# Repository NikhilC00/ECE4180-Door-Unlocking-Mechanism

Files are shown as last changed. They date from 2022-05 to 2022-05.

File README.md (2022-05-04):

# ECE4180-Door-Unlocking-Mechanism

Team Members: Audrey Ahlenius and Nikhil Chittaluru

## What is it?

**Problem**: Automatic locking doors in Georgia Tech housing buildings result in students getting locked out

**Solution**: A product that will unlock your door via bluetooth or a touch pad

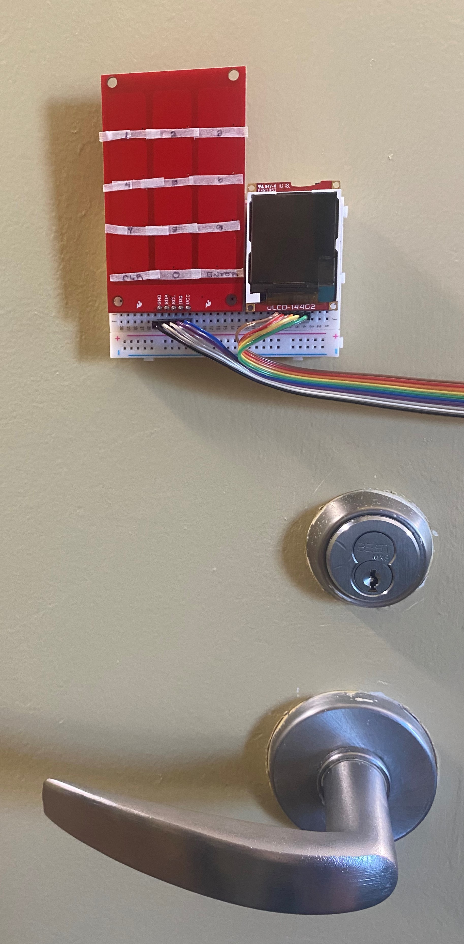
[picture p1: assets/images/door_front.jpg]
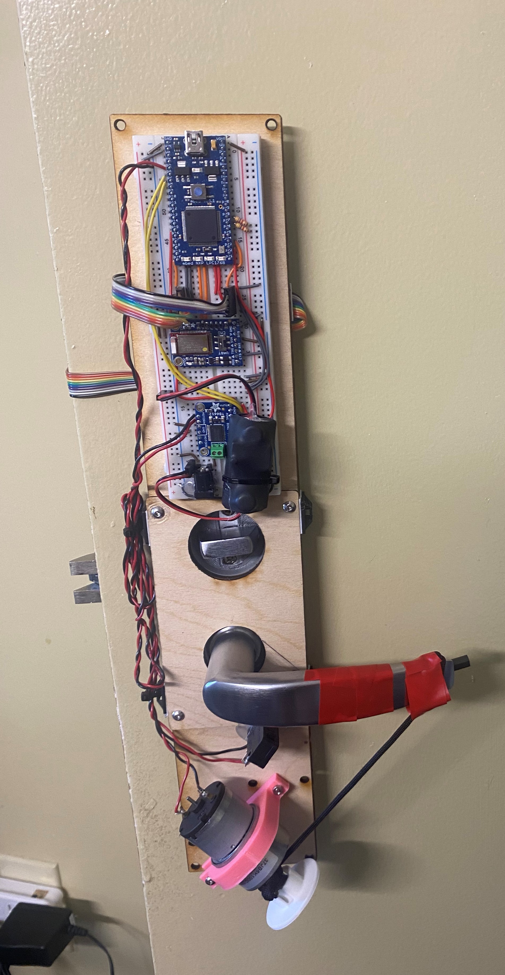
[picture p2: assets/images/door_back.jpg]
 

## Hardware

Here is what our system looks like:

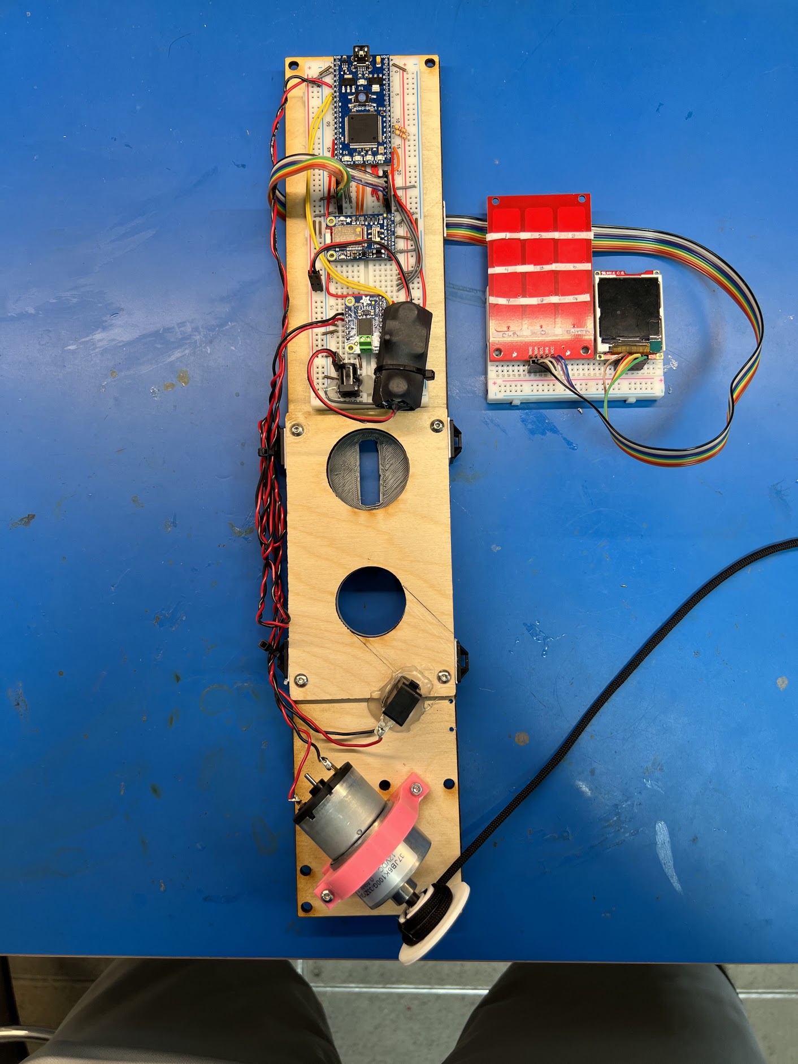
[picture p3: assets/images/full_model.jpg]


**Modules**: Main Electronics Board, Door UI, Door Handle Motor (from left to right)

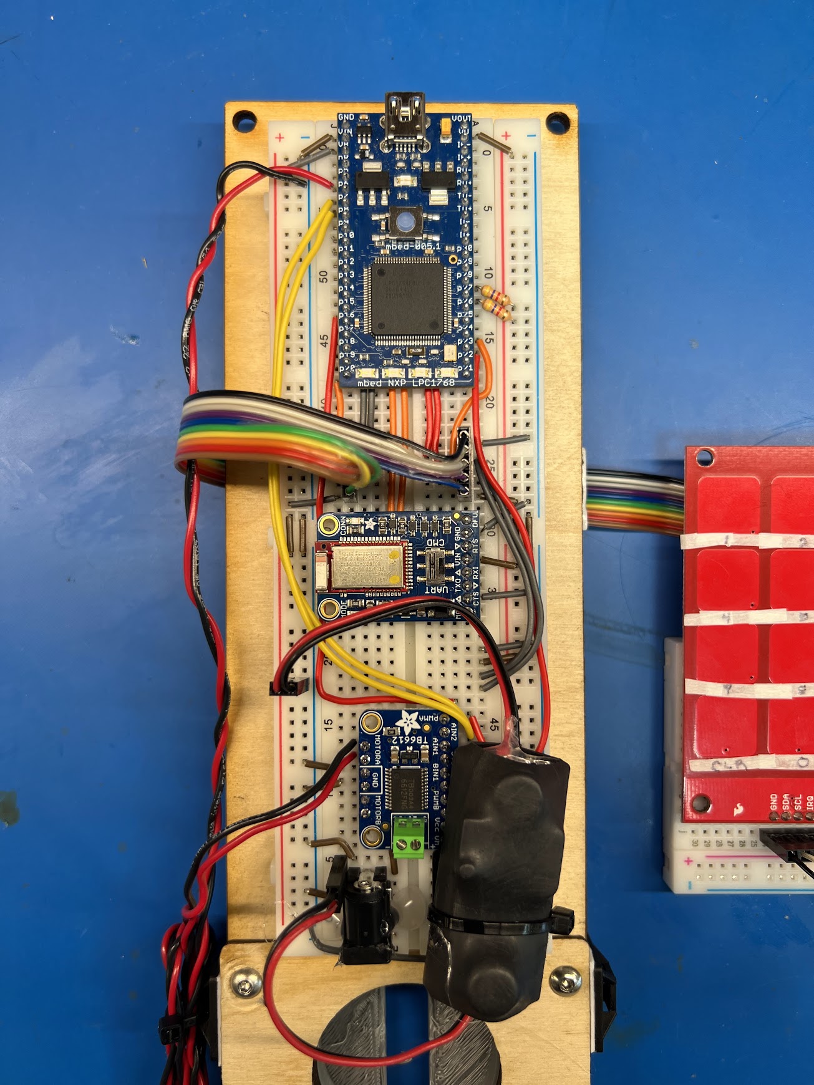
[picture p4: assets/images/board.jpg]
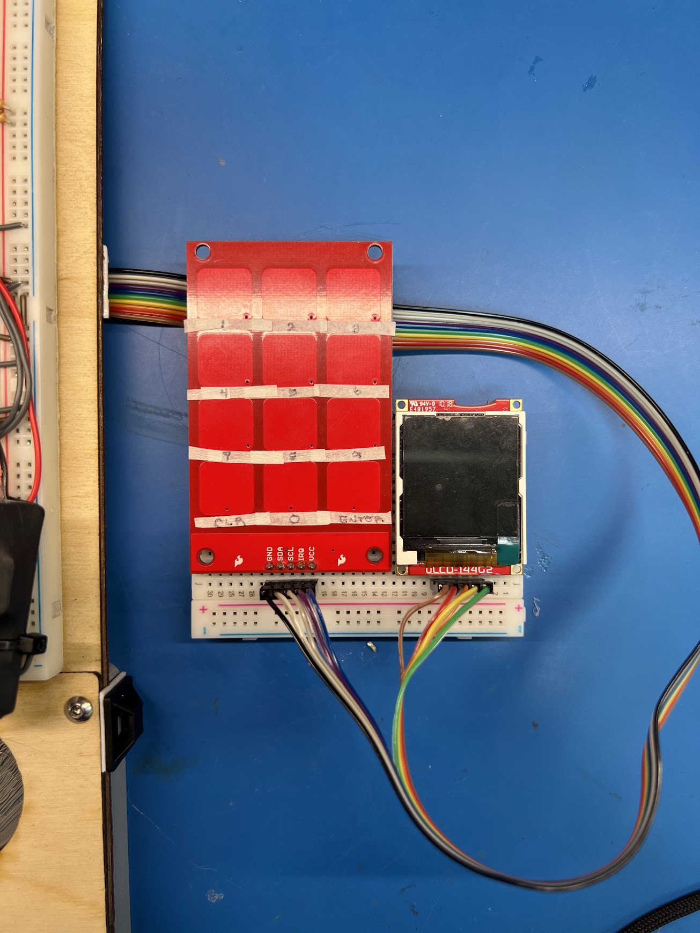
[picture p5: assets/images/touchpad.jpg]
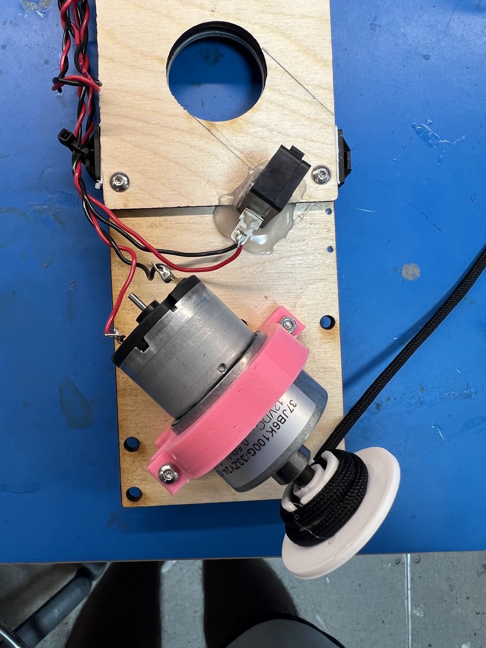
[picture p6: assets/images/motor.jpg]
  

**Side Profiles**:

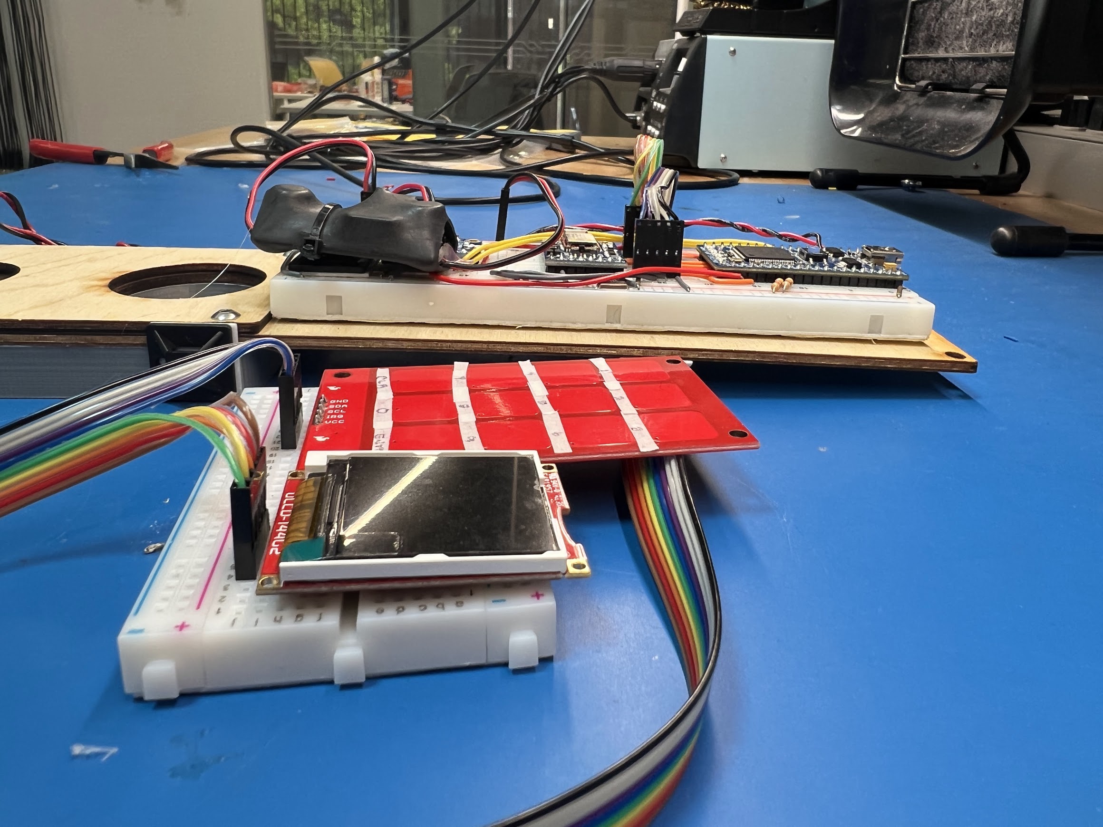
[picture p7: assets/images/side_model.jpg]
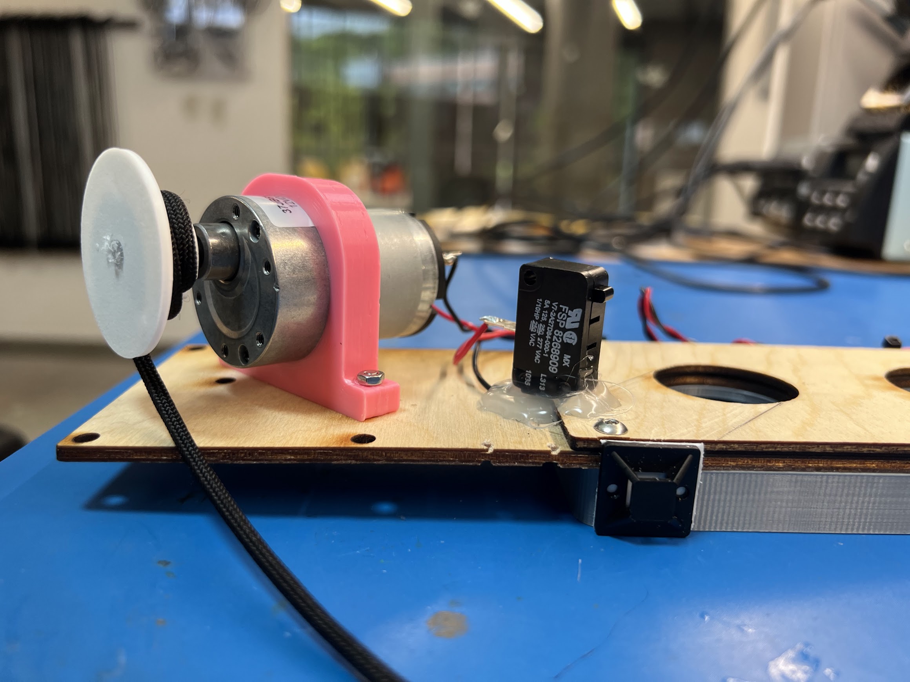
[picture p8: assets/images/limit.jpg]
 

More details about the hardware can be found below

#### Door Mount

This is the hardware for mounting our device to the door frame. It fits around the doors locking system so that it does not interfere with the actual door lock mechanics. There is a 3D printed mount that fastens the system to the door without using tape. It can also be adjusted depending on the type of door lock system.

See the `/assets/cad` file to find all the STEP files for the components fo the door mount. Each plate was cut from 0.125" birch wood using a laser cutter. The other components were made using a 3D printer.

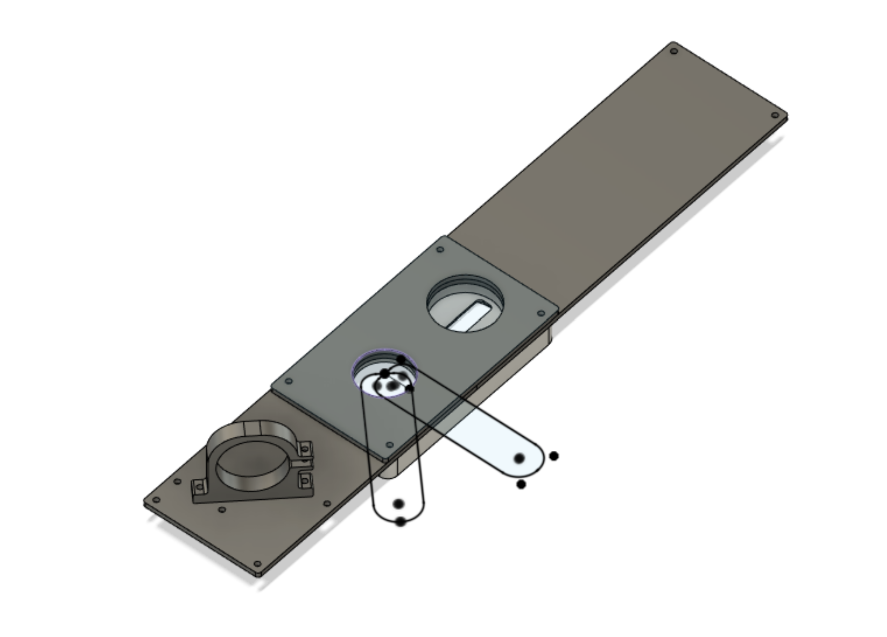
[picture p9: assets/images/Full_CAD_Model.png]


#### Electronics Parts List

##### mbed



https://www.sparkfun.com/products/9564

##### uLCD


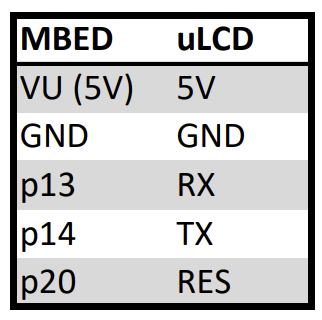
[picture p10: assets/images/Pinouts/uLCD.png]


https://4dsystems.com.au/ulcd-144-g2

##### H-Bridge Motor Driver


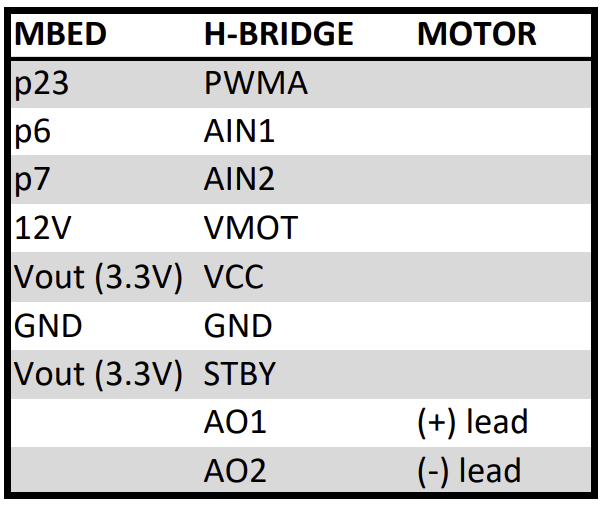
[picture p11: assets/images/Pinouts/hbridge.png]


##### Capacitive Touchpad


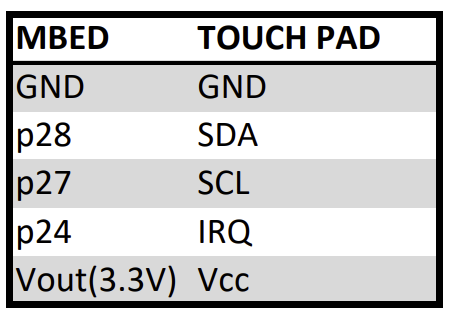
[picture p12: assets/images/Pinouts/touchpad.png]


https://www.sparkfun.com/products/retired/10250

##### Bluetooth Module


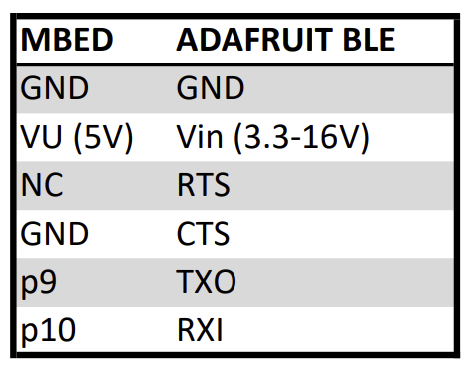
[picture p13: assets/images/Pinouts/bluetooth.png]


https://www.digikey.com/en/htmldatasheets/production/1801441/0/0/1/bluefruit-le-uart-friend.html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

##### 12V DC motor



http://www.zgcmotors.com/pro/37jb6k-33zy24/

##### DC-DC converter



https://www.amazon.com/Dafurui-Adjustable-Converter-3-0-40V-Regulator/dp/B08CGL6FQD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

##### 12V Power Adapter



https://www.amazon.com/MyVolts-supply-adaptor-compatible-CG2412-B/dp/B012TMPGUU?th=1

### Software

The software has two threads and two interrupts. Overall, it checks when a user submits a passcode. If the passcode is correct, it runs an open-door sequence. If the passcode is wrong, it tells the user using the LCD screen.

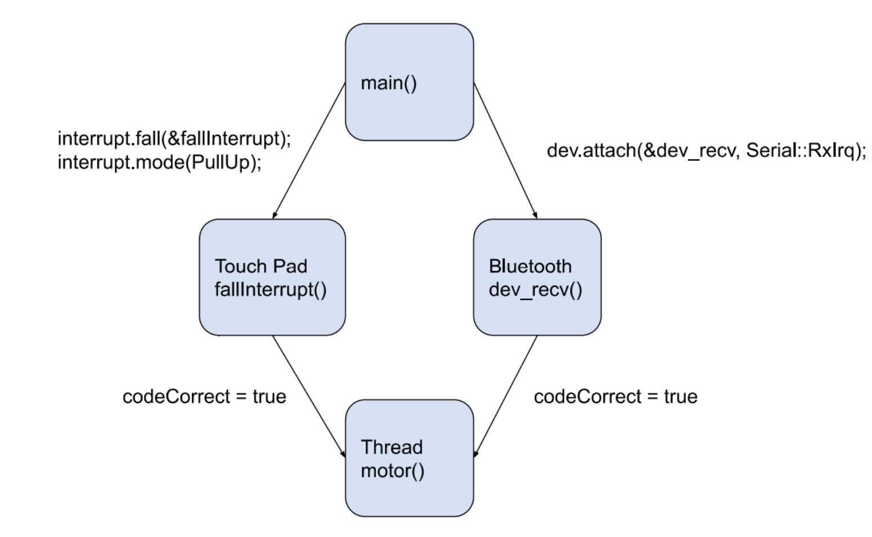
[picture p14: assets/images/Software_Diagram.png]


**Threads**:

* The `main` thread handles the user input through either the capacitive touch pad or the bluetooth module. It also displays the updated inputs to the LCD screen based on boolean flags raised by the interrupts. When a flag is raised, the thread checks the user-inputted passcode with the set passcode. If the two match, it raises a flag to let the motor thread know to run the open-door sequence.
* The `motor` thread runs the open-door sequence to let the user into the room. Once it sees the flag raised by the main thread, it turns on the motor and starts a timer. Once the door handle hits a limit switch (indicating the door is open), the motor and timer both stop. The thread waits 5 seconds for the user to enter the room before running the motor backwards for the open sequence duration (based on the timer). 

**Interrupts**:

* The Bluetooth interrupt handles when a message is received from the Bluefruit Module serial port. It goes through the received message and creates a passcode buffer. It then raises a flag for the main thread to check the buffer against the set passcode.
* The Capacitive Touchpad interrupt runs whenever it detects a change in input from the pad. Each pad is correlated with a binary value which is then converted to a `char` representing a number `0-9`, `clear`, `enter`, or `no entry`. It saves the sequence of numbers with each pad press. If:
  * `clear` is pressed, the buffer is cleared
  * `enter` is pressed, it raises a flag to check the buffer against the set passcode.

### Results and Future Work

The door is unlocked through a password entered via Bluetooth or on the Touchpad so we met the project goals! See the video demos below:

###### Demo: Outside the Door

https://www.youtube.com/watch?v=1BmhXal_50E&ab_channel=AudreyAhlenius

###### Demo: Inside the Door

https://youtube.com/shorts/F9PI_cVdQdg?feature=share

###### Demo: Bluetooth Password Input

https://youtube.com/shorts/ofLp8rDiyAs?feature=share

**Potential Improvements:**:

While the system works well, these are some ways to improve the system 
* Add Bluetooth User interface: buttons, message sending, GUI
* Reduce profile with a PCB
* Include a fingerprint scanner for door lock input
* Use a distance sensor (instead of limit switch) for different door styles

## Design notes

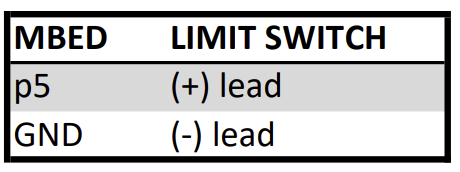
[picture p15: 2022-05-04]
assets/images/Pinouts/switch.png

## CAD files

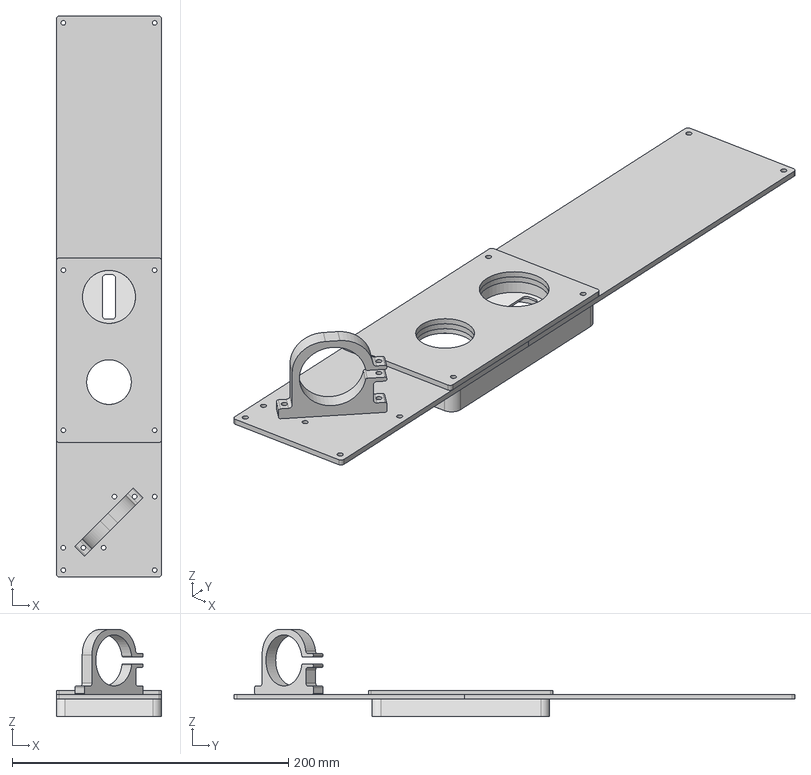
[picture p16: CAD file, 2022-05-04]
assets/cad/Door Mount Assembly v5.step
76.2 x 406.5 x 63.2 mm
Inside_Door_Base_V1
Inside_Door_Motor_Cap_V1
Motor Mount
Electronics Plate
Motor Plate
Cover

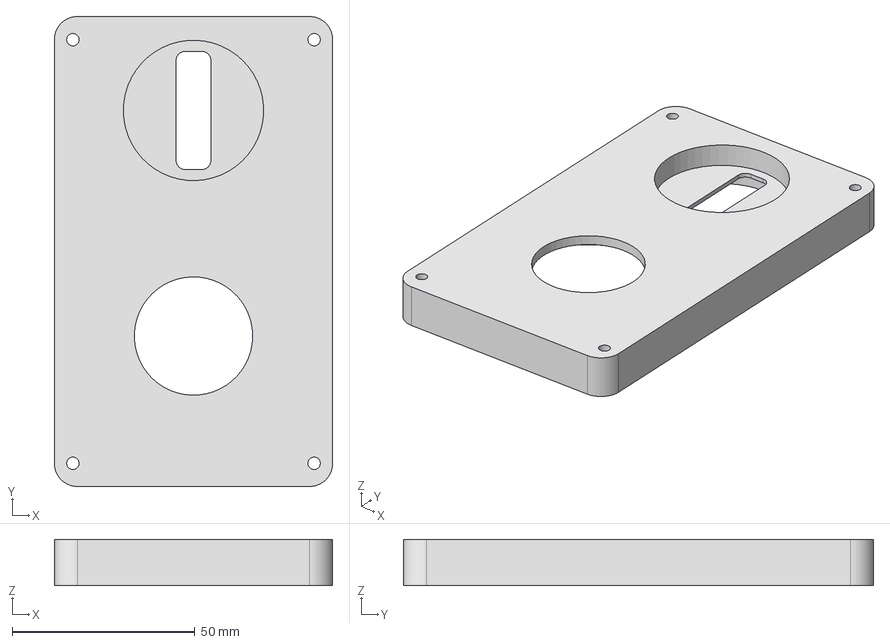
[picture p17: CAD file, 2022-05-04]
assets/cad/NewDoorMount v4.step
76.2 x 128.7 x 12.7 mm
Inside_Door_Base_V1
Inside_Door_Motor_Cap_V1

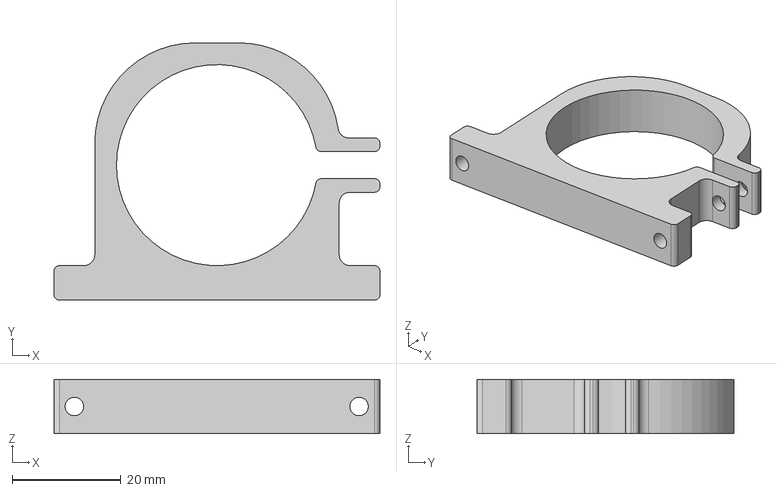
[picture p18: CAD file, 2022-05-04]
assets/cad/Motor Mount v2.step
60.0 x 47.3 x 10.0 mm

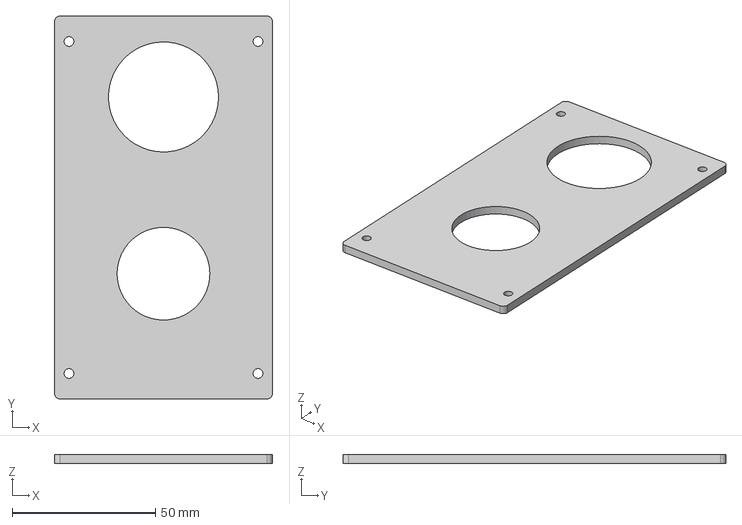
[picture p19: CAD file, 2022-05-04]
assets/cad/Cover v5.step
76.2 x 133.8 x 3.17 mm

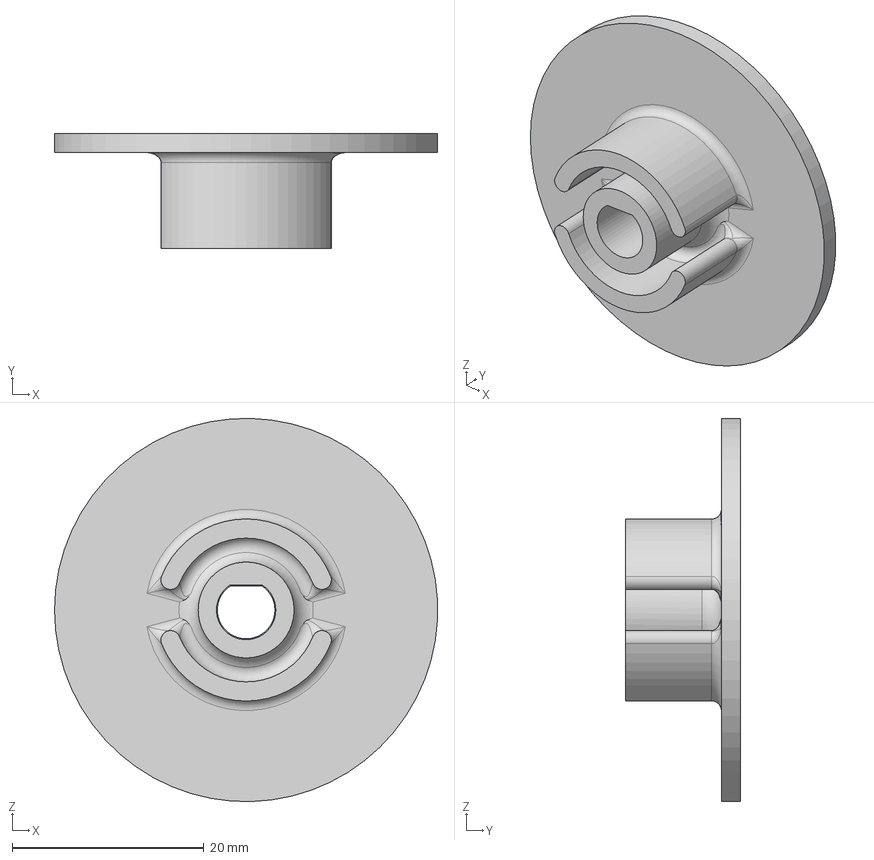
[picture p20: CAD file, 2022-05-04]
assets/cad/Motor Cap v5.step
40.0 x 12.0 x 40.0 mm

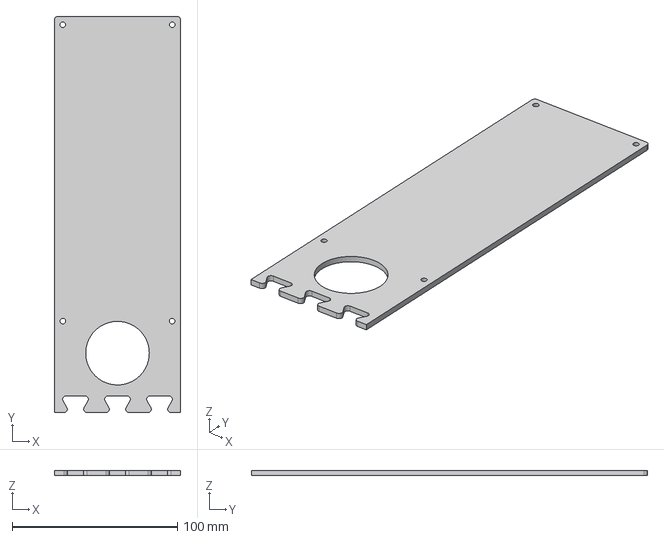
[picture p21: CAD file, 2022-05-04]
assets/cad/Electronics Plate v4.step
76.2 x 239.4 x 3.18 mm

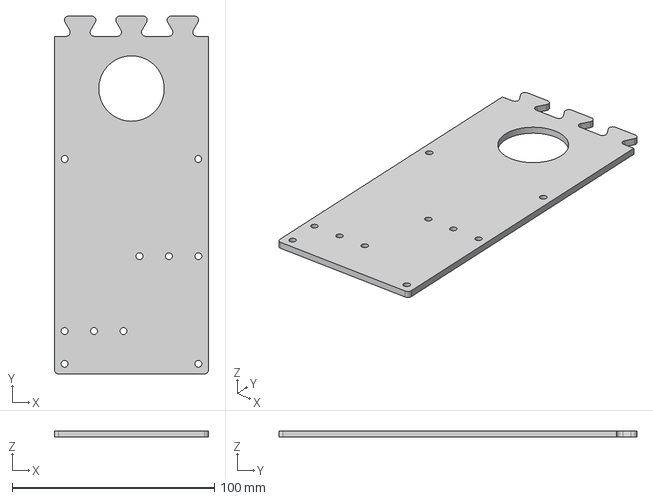
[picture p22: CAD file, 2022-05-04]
assets/cad/Motor Plate v4.step
76.2 x 177.1 x 3.17 mm

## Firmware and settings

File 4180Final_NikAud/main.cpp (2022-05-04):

// 4180 Final Project Code - Nikhil and Audrey

// Product will have two inputs: passwords from bluetooth (lab3_5) and touchpad (lab1_6) 
// If the password is correct, a DC motor will run and unlock the door
// Instructions will be displayed on a uLCD (lab2_3)


// 1-9: numbers, 10: back, 11: 0, 12: enter 
// 8 digit password 


#include "mbed.h"
#include "LSM9DS1.h"
#include "uLCD_4DGL.h"
#include <mpr121.h>
#include "Motor.h"
#include "XNucleo53L0A1.h"
#include <stdio.h>
#include "rtos.h"
//#include <VL53L0X.h>


char passcode[9] = {'1', '2', '3', '4', '4', '3', '2', '1'};

DevI2C i2c(p28, p27);//DevI2C i2c(p9, p10); // Setup the i2c bus on pins 9 and 10
uLCD_4DGL uLCD(p13,p14,p20);//uLCD_4DGL uLCD(p13,p14,p11); // serial tx, serial rx, reset pin;
InterruptIn interrupt(p24);// Create the interrupt receiver object on pin 24

Serial pc(USBTX, USBRX);// Setup the Serial to the PC for debugging
RawSerial dev(p9, p10); //RawSerial dev(p28,p27);
Motor m(p23, p6, p7); // pwm, fwd, rev LEFT motor
//Motor m(p22, p25, p26);// Motor m(p23, p6, p5); //pwm, fwd, rev
DigitalOut shdn(p15);//DigitalOut shdn(p26); //Lidar sensor

DigitalOut mtr1(p6);//DigitalOut shdn(p26); //Lidar sensor
DigitalOut mtr2(p7);//DigitalOut shdn(p26); //Lidar sensor


//VL53L0X sensor(SENS1_PIN4, SENS1_PIN3);
DigitalIn limSwitch(p5);

Mutex LCD;
Timer t;

DigitalOut led1(LED1);
DigitalOut led2(LED2);
DigitalOut led3(LED3);
DigitalOut led4(LED4);


//I2C sensor pins - CHANGE PIN NUMBERS ?
#define VL53L0_I2C_SDA   p28
#define VL53L0_I2C_SCL   p27

// Setup the Mpr121: Capacitive Touch
Mpr121 mpr121(&i2c, Mpr121::ADD_VSS); // constructor(i2c object, i2c address of the mpr121)

//Global Variables
char tpCode[9];
int tpCount = 0;
char btCode[9];

const int kMaxBufferSize = 100;
char      buffer[kMaxBufferSize];
int       len = 0;

char      buffer2[kMaxBufferSize];
int       len2 = 0;

volatile int btCount = 0;
volatile bool codeCorrect = false;

volatile int value; 
volatile bool keyDetect = false;

volatile bool newCode = false;
volatile char temp;

void fallInterrupt() {
    led3 = !led3;
    value = mpr121.read(0x00);
    value += mpr121.read(0x01)<<8; //**What does this do? 
    keyDetect = true;
    switch (value) {
        case 0:
            temp = 'x'; //no key
            break;
        case 1:
            temp = 'c';
            break;
        case 2:
            temp = '7';
            break;
        case 4:
            temp = '4';
            break;
        case 8:
            temp = '1';
            break;
        case 16:
            temp = '0';
            break;
        case 32:
            temp = '8';
            break;
        case 64:
            temp = '5';
            break;
        case 128:
            temp = '2';
            break;
        case 256:
            temp = 'e';
            break;
        case 512:
            temp = '9';
            break;
        case 1024:
            temp = '6';
            break;
        case 2048:
            temp = '3';
            break;
    }
    if(temp == 'e') {
        newCode = true;
        buffer2[len2] = '\0';
        buffer2[8] = '\0';
        len2 = 0;
    } else if (temp == 'c') {
        len2 = 0;
        buffer2[len2] = '\0';
    } else if (temp == 'x') {
        // do nothing?
    }else {
        buffer2[len2++] = temp;
        buffer2[len2] = '\0';
    }
}

volatile int closed;

void motor(void const *args) {
    limSwitch.mode(PullUp);

    while(1) {
        led2 = !limSwitch;
        if(codeCorrect) {
            led4 = 1;
            closed = limSwitch;
            m.speed(1);
            t.start();
            for(int i = 0; i < 5000; i++){
                if (!limSwitch) break;
                Thread::wait(1);
            }
            m.speed(0);
            t.stop();
            led4 = 0;
            Thread::wait(5000);
            led4 = 1;
            float spinTime = t.read();
            t.reset();
            m.speed(-1);
            LCD.lock();
            uLCD.locate(0,12);
            uLCD.printf("sTime: %f", spinTime);
            Thread::wait(50);
            LCD.unlock();
            Thread::wait(spinTime * 1000);
            m.speed(0);
            codeCorrect = false;
        }
        led4 = 0;
        Thread::wait(100);
    }    
}

volatile bool newThing = false;

void dev_recv() {
    led1 = !led1;
    
    while(dev.readable()) {
        char new_char = dev.getc();          
        buffer[len++] = new_char;    
    }
    buffer[len] = '\0';
    buffer[8] = '\0';          
    newThing = true;

}

int main() {
    uLCD.cls(); // clear LCD
    uLCD.text_height(1); // Set text size to 2
    uLCD.text_width(1); // Needed w/ prev line
    uLCD.color(BLUE); // Set color to: (BLACK, RED, GREEN, BLUE, RED+GREEN, ect.)
    uLCD.locate(0,1); // Set cursor to (col, row)
    uLCD.printf("Enter passcode on phone or keypad");

    
    interrupt.fall(&fallInterrupt);
    interrupt.mode(PullUp);
    
    dev.baud(9600);
    dev.attach(&dev_recv, Serial::RxIrq);
    Thread thread1(motor);
    
    while(1) {
        LCD.lock();
        if(newThing) {
            len = 0;
            //uLCD.locate(0, 6); // Set cursor to (col, row)
            //uLCD.printf("buffer: %s", buffer);
            uLCD.locate(0, 7); // Set cursor to (col, row)
            if(strcmp(buffer, passcode) == 0) {
                uLCD.printf("RIGHT");
                codeCorrect = true;
            } else {
                uLCD.printf("WRONG");
                codeCorrect = false;
            }
            newThing = false;
        } else if(newCode) {
            uLCD.locate(0, 9); // Set cursor to (col, row)
            if(strcmp(buffer2, passcode) == 0) {
                uLCD.printf("RIGHT");
                codeCorrect = true;
            } else {
                uLCD.printf("WRONG");
                codeCorrect = false;
            }
            newCode = false;
        }
        if (led4) {
            uLCD.locate(0, 10); // Set cursor to (col, row)
            uLCD.printf("Closed: %d", closed);
        }
        if(keyDetect) {
            uLCD.locate(0, 4); // Set cursor to (col, row)
            uLCD.printf("         ");
            uLCD.locate(0, 4); // Set cursor to (col, row)
            uLCD.printf("t: %c", temp);
            uLCD.locate(0, 8); // Set cursor to (col, row)
            uLCD.printf("              ");
            uLCD.locate(0, 8); // Set cursor to (col, row)
            uLCD.printf("b2: %s", buffer2);
            keyDetect = false;
        }
        LCD.unlock();
        
        Thread::wait(50);
    }
}
